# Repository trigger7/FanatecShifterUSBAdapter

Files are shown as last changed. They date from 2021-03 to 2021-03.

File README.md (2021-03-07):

# Fanatec Shifter USB Adapter
Standalone USB adapter for Fanatec Clubsport Shifter SQ v1.5

Built using a Teensy LC and PlatformIO

Works using software hysteresis to prevent bouncing.

## Preliminary note
If all you need is connecting your Fanatec shifter to a USB port, your best bet is to purchase the official adapter.

The main advantage of this project is to modify it to include other peripherals, extra buttons, etc

## Thanks
Big thanks to [summivox](https://github.com/summivox) for inspiring me to make my own adapter, and for providing much helpful details about the shifter.

You can find his work about this at

 * hackaday : [wiring and reverse engineering](https://hackaday.io/project/171155-fanatec-clubsport-shifter-sq-v15-usb-adapter-diy)
 * github : [arduino code](https://gist.github.com/summivox/cfbcb8d309d416cefc3c0df10379339f)

## Wiring
I used an RJ12 jack (6P6C) so I could plug the cable bundled with the shifter.

Wire as following :

| RJ12  | Teensy LC |
| ----- | --- |
| pin 1 | GND |
| pin 2 | unused |
| pin 3 | pin 14 |
| pin 4 | pin 15 |
| pin 5 | pin 16 |
| pin 6 | 3.3V |

 Warning : do not use 5V if your microcontroller's pins aren't 5V tolerant !

You can of course use other pins, adjust the code as necessary.

## X axis

I decided to implement software hysteresis instead of traditional debouncing. Mostly for fun, I guess...

I also tried smoothing/filtering, but it seemed unnecessary. Especialy with the ADC set to 11 bits precision (instead of the maximum 12 bits).
There are unused leftovers of my attempt at smoothing, dig it up and activate it if you need/want.

### Calibration

I tried to auto-calibrate the X axis, with mixed results. It almost works, but as the gates of the shifter aren't evenly spaced, I had gear 4 sometimes "bleed" into gear 2.

I ended up hard-coding the values.
If you need to adjust these for your shifter :

 * Activate debug (uncomment [this line](https://github.com/trigger7/FanatecShifterUSBAdapter/blob/main/src/main.cpp#L5))
 * Upload the code onto your microcontroller
 * Open the serial monitor
 * Engage each odd gears (including 7th and reverse) and look at the X value on the serial monitor
* Take note of the average value for each gear
* Replace the values [here](https://github.com/trigger7/FanatecShifterUSBAdapter/blob/main/src/main.cpp#L70) with yours, in descending raw value, ascending gear order (reverse, 1st, 3rd, 5th, 7th). The 32 at the end is the deadband for hysteresis, leave it as is.
* Recompile and reupload

## Y axis
The Y axis seems very stable and consistent, it shouldn't need any adjustment.

## Extra stuff

### USB Device name
I've included a file to customize the USB name under which the Teensy will appear. The Vendor ID and Product ID, however, are still the same.

If you are using or have been using a Teensy LC (or the same model as the one you're making your shifter adapter with), you may encounter issues because Windows is caching device names.

In this case, you can either :
 * remove usb_name.c and use the default name
 * create a custom Vendor/Product ID (no easy way to do this ; search PJRC forum)
 * open the Windows registry and do some clean-up (at your own risk !)

### Other microcontrollers
Other microcontrollers will probably work too. Other Teensys (Teensies?) in particular shouldn't need any modification.

For Arduinos (Arduini?), you will need to use the Joystick library instead of the "native" support from the Teensy.

### Arduino IDE
Converting to the Arduino IDE should be straightforward (rename src/main.cpp to <your_sketch>.ino and add the .h files from the include directory).

For Teensy, don't forget to set the USB type to "Serial + Keyboard + Mouse + Joystick". You can also downclock the CPU (I set my LC to 24MHz with "Fastest with LTO" optimization).

### Other shifters
It should be possible to use the same approach for the Logitech G25/G27/G29 shifters. As far as I know, they also use 2 analog axes for the gear stick.
Code will need extensive modifications though (different wiring, different number of gears, different sequential mode)...

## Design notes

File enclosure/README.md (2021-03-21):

# Fanatec Shifter USB Adapter Enclosure

Here is a 3D printed enclosure for the USB Adapter.

It is designed to fit a Teensy LC, a straight RJ12 jack (6P6C) and 2.54mm pin headers for extra connectivity.

## Tolerances

The enclosure has been designed with my printer and ABS in mind. As such, tolerances have been added for this purpose (approximatively 0.1 to 0.2 mm on every side of holes/pockets).

The FreeCAD source file is included on case you need to make adjustements.

Please note that, due to the way the enclosure is designed/built, you can modify any length/diameter constraint in any sketch (and the whole design will update), but all other modifications will likely break the object.

## RJ12 jack

The straight 6P6C jack used was bought at a local electonics store, but seems like a common design. It can be recognized by 2 small ribs on each side.

## Pin headers

For the pin header, 9 pins are available. Cut a length of 11 pins, but remove one pin en each side. This extra length is used to secure the headers to the top cover of the enclosure.

These pins can be used as needed, and will require modification to the code (they are not implemented by default).

For example, you can use them for 8 buttons (1 common ground + 8 pull-up inputs), 2 rotary encoders (common ground and 3.3V + 3 pins per encoder), or anything in between.

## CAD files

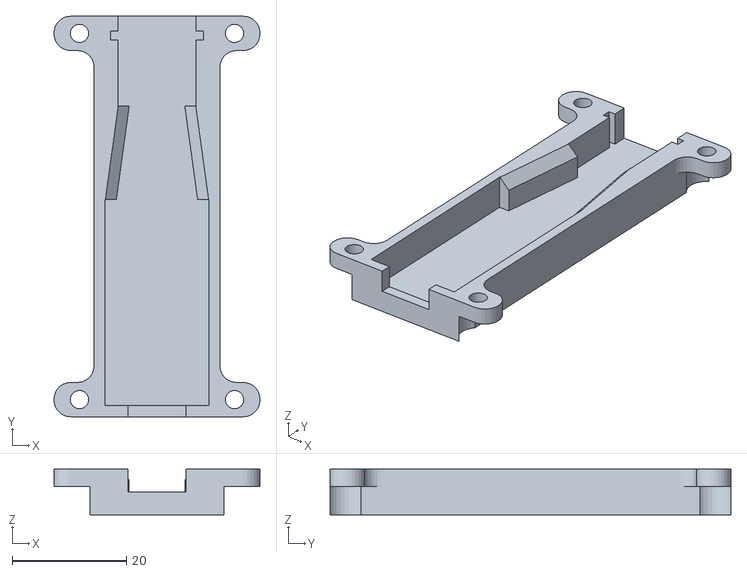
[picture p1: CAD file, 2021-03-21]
enclosure/shifter_usb_adapter_bottom.stl
36.0 x 70.0 x 8.00

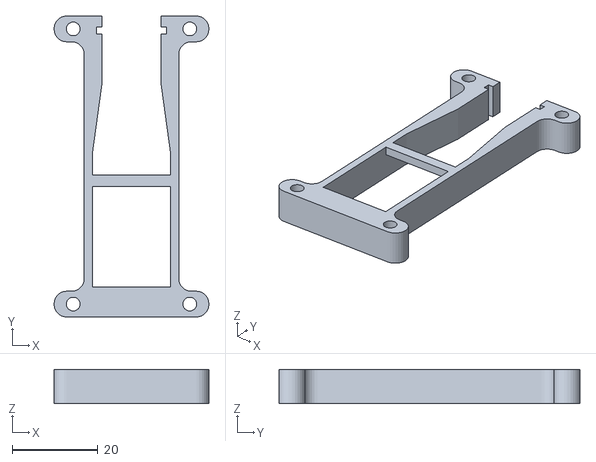
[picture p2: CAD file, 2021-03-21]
enclosure/shifter_usb_adapter_middle.stl
36.0 x 70.0 x 8.00

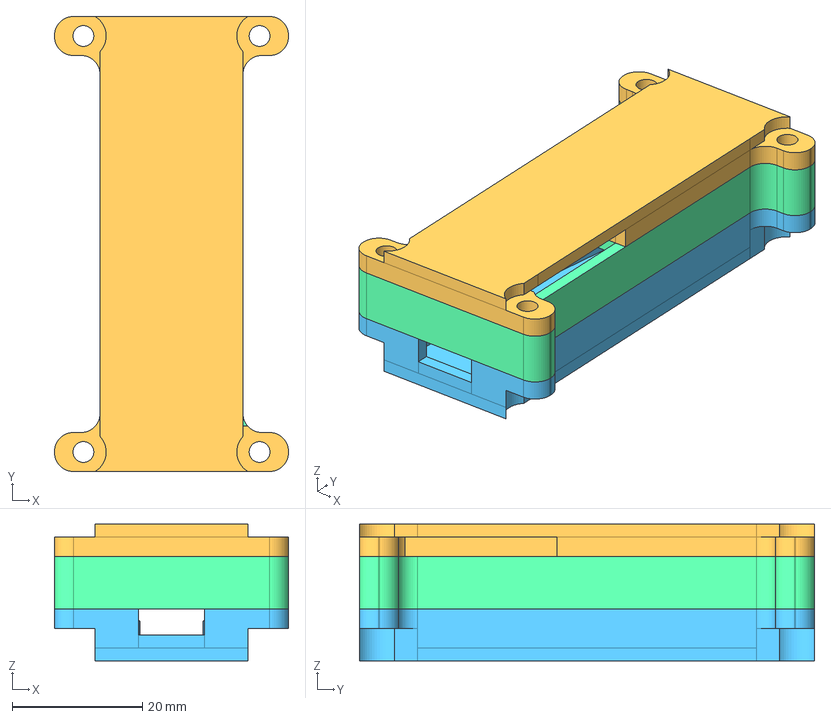
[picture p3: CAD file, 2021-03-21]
enclosure/shifter_usb_adapter.FCStd
36.0 x 70.0 x 21.0 mm
Bottom
Middle
Top

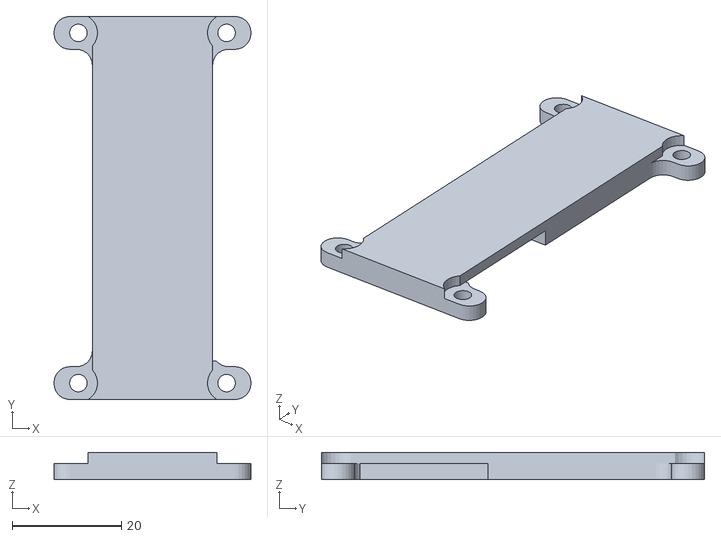
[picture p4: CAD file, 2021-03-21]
enclosure/shifter_usb_adapter_top.stl
36.0 x 70.0 x 5.00

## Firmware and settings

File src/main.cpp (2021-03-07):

#include <Arduino.h>
#include "Smooth.h"
#include "Hysteresis.h"

//#define DEBUG


template <typename T>
class HShifter : public Printable
{
  public:
    int8_t gear = 0;
    HShifter(T reverse, T first, T third, T fifth, T seventh, T x_deadband, T down, T up, T y_deadband) :
       _HX(seventh, fifth, third, first, reverse, x_deadband), _HY(down, up, y_deadband) {}
    int8_t update(T x, T y)
    {
      _HX.update(x);
      _HY.update(y);
      if (_HY.low && !_HY.high) {
        gear = 0; // Neutral
      } else if (!_HY.low) {
        if (_HX.highest)
          gear = -2;  // not possible
        else if (_HX.high)
          gear = 2;
        else if (_HX.low)
          gear = 4;
        else if (_HX.lowest)
          gear = 6;
        else
          gear = -2;  // not possible
      } else {
        if (_HX.highest)  // X-axis is reversed
          gear = -1;
        else if (_HX.high)
          gear = 1;
        else if (_HX.low)
          gear = 3;
        else if (_HX.lowest)
          gear = 5;
        else
          gear = 7;
      }
      return gear;
    }
    size_t printTo(Print& p) const {
      size_t r = 0;
      r += p.print(" X : ");
      r += p.print(_HX);
      r += p.print(" Y : ");
      r += p.print(_HY);
      r += p.print(" gear : ");
      r += p.print(gear);
      return r;
    }

  private:
    FiveWayHysteresis<T> _HX;
    ThreeWayHysteresis<T> _HY;
};


//Smooth SmoothX = Smooth(A1);
//Smooth SmoothY = Smooth(A2);

// Tune threshold and deadband numbers if not using 11 bits ADC
Hysteresis<uint16_t> SeqX = Hysteresis<uint16_t>(1024, 128);
Hysteresis<uint16_t> SeqY = Hysteresis<uint16_t>(1024, 128);
// Average X value for gear :              R    1st   3rd  5th  7th
HShifter<uint16_t> H = HShifter<uint16_t>(1495, 1165, 775, 425, 135, 32,
                                          512, 1536, 256);

// Used to remember previous values and update Joystick buttons only when necessary
bool old_down = false;
bool old_up = false;
int8_t old_gear = 0;


void setup() {
#ifdef DEBUG
  Serial.begin(115200);
#endif
  pinMode(14, INPUT);
  analogReadResolution(11); // 12 bits ADC is very jittery and offers no extra info over 11 bits
  Joystick.useManualSend(true);
  // Center everything
  Joystick.hat(-1);
  Joystick.X(512);
  Joystick.Y(512);
  Joystick.Z(512);
  Joystick.Zrotate(512);
  Joystick.sliderLeft(512);
  Joystick.sliderRight(512);
  Joystick.send_now();
}


void loop() {
  const bool seq = digitalRead(14);
  //const uint16_t x = SmoothX.read();
  //const uint16_t y = SmoothY.read();
  const uint16_t x = analogRead(A1);
  const uint16_t y = analogRead(A2);

  if (seq == true) {
    // Seq shifts are active low
    const bool down = !SeqX.update(x);
    const bool up = !SeqY.update(y);
    if (down != old_down || up != old_up) {
      Joystick.button(9, down);
      old_down = down;
      Joystick.button(10, up);
      old_up = up;
      Joystick.send_now();
    }
  } else {
    const int8_t gear = H.update(x, y);
    if (old_gear != gear) {
      // We only engage a gear from neutral (old_gear == 0)
      // This is necessary because during fast shifts, the Y axis would lag behind the X axis
      // As a result, for example, the 4th gear would briefly register during a 2nd to 3rd shift
      if (gear > 0 and old_gear == 0) Joystick.button(gear, true); // Not neutral or reverse
      if (gear == -1) Joystick.button(8, true); // Reverse
      if (old_gear > 0) Joystick.button(old_gear, false);
      if (old_gear == -1) Joystick.button(8, false);
      old_gear = gear;
      Joystick.send_now();
    }
  }

#ifdef DEBUG
  char text[5];
  Serial.print("X : ");
  sprintf(text, "%04d", x);
  Serial.print(text);
  Serial.print(" Y : ");
  sprintf(text, "%04d", y);
  Serial.print(text);
  Serial.print(" mode : ");
  Serial.print(seq ? "SEQ" : "H");
  if (seq == true) {
    Serial.print(" X : ");
    Serial.print(SeqX);
    Serial.print(" Y : ");
    Serial.println(SeqY);
  } else {
    Serial.println(H);
  }
#endif
}

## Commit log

2021-03-07 Small fix and refactoring
    [main.cpp]
2021-03-07 Fixed "phantom" gears during fast shifts
    [main.cpp]
2021-03-07 Added wiring info
2021-03-21 Added 3D printed enclosure
    [shifter_usb_adapter.FCStd, shifter_usb_adapter_bottom.stl, shifter_usb_adapter_middle.stl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]
